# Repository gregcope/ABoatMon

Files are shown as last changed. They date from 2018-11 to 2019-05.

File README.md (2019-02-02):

ABoatMon
========

An Arduno clone based (hence the A) Boat Monitoring solution!

Intro
=====

A reimplementation, and extension of https://github.com/gregcope/piboatmon, as the original consumed too much power.  This is designed with the following goals;
* Be very, very low power and
* Monitor and charge from 12-24V

The present version is made from COTS parts to make life easy at the deign/proto stage.  However the code should be transferable.

Parts
=====
* [Adafruit Ultimate GPS](https://www.adafruit.com/product/746) - any 3.3v UART GPS would do, however needs an enable pin and vbat GPS almanac backup
* [Adafruit Fona](https://www.adafruit.com/product/1946) - any 3.3v UART GSM modem would do, although we do use the battery charging on the fona
* [Low power Atemega 1280 Moteino Mega](https://lowpowerlab.com/shop/product/119) This might fit into lower spec Atmegs, but I have no idea... The [Moteino M0 would work well](https://lowpowerlab.com/shop/product/184), although pin outs need to change.
* [Mini Step Down Regulator Voltag Power Supply Module 4.5v~55v to 5v](https://www.ebay.co.uk/sch/i.html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).  Specifically the one with an enable pin and low power in off mode (<10ua).  Needs to supply 500ma+ (600ma is fine) and deal with 11-30v on the input to work on 12V or 24V systems.  Needs to supply 5V for the lipo charger.  Efficiency is not a massive issue as the regulator is off most of the time, only on to charge occassionally.
* [DS18B20 Waterproof Digital Probe Temperature Sensor with Silicone Cable (higher temp) Thermometer](https://www.ebay.co.uk/sch/i.html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)
* [12V 12mm LED Power Push Button Switch Momentary Waterproof Metal 4 Pin](https://www.ebay.co.uk/sch/i.html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)
* 1200mah LIPO Battery (any single cell LIPO with a JST would do)
* Bilge Switch (any normally closed, simple switch would do)

External Libs
=======

* [Tinygps++](https://github.com/mikalhart/TinyGPSPlus) - A class to deal with GPS
* [Lowpower](https://github.com/LowPowerLab/LowPower) - A class to help with Sleep modes
* Eeprom - Save Eeprom state
* [OneWire](https://github.com/PaulStoffregen/OneWire) - DS18B20 Temp sensor lib

Internal Classes
========
* Config - A class to provide a config object to store Eeprom state
* CRC8 - CRC checksum (for config saving)
* Sleep - Simple wrapper to LowPower sleep
* Buton - A simple button monitor
* Fona - Drive a fona to send data
* Gps - Drive a GPS and feed a TinyGPS++ object with other helper methods
* Led - A simple LED driver
* Lipo - A class to ADC a Lipo value
* Temp - A class with simple, non-sleeping temp measurements
* Vcc - A class to ADC the VCC, as well as enable/disable a regulartor (that drives the 5v Lipo charger)

High Level Logic
================

* Switches is on setup configures all the required parts
* Loop every 8 secs and checks;
   * Start the temp conversion 
   * Lipo volts
   * VCC (and enable regulator if Vcc > 13 and switch off if low)
   * Bilge switch
   * read temp (blocks)
* Every Hour;
   * Checks the above
   * Checks location
* If out of band, send a message as an alarm
* Daily
   * Send a message

VCC logic - Sacrifical Charging
================
The idea is that if VCC is 13v plus then a charge source is on and we can hence enable the regulator.  If the VCC is above REG_ON_VOLTS (13v) enable the regulator to start the LIPO charger.  If below REG_OFF_VOLTS (12.8) stop regulator

Message Sending
================
To save possible expensive bandwidth the message is compressed.  Ideally it would be JSON.  However it is optimised for speed and bandwidth costs.  It needs to be parsed on arrival.

HowTo
=====

1. Open a command terminal, and change cd to where your Ardunio IDE stores code
```cd Documents/Arduino```
2. Clone the repo
```git clone https://github.com/gregcope/ABoatMon.git```
3. Open Ardunio IDE and open ```ABoatMon.ino```

http://arduino.stackexchange.com/questions/348/how-to-organize-my-arduino-projects-structure-for-easy-source-control

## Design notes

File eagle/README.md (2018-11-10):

# Eagle Files

0. Uses Sparkfun DRC file
1. ERC and DRC check clean!
2. Bottom Copper Pour
3. Nets Classes use 24mil width and 16mil clearance
4. Polygons use Isolate 12mil
5. Layer 26 bNames - bottom silkscreen has board dimensions on it

## Design

0. I may add more parts...
1. Uses a MoteinoMega, Adafruit Ultimate GPS and an Adafruit FONA GSM
2. The P-channel Mosfet is designed to power the GPS directly, avoiding the on board regulator
3. The VBAT is on the MotinoMega 3.3V rail to keep the GPS backup circuits powered
4. The JST is for a Lipo battery
5. Their is a 1.8M/3.3M VCC voltage divider to monitor the LIPO, with a 0.1uF capacitor - see [Jeelabs post here](https://jeelabs.org/2013/05/16/measuring-the-battery-without-draining-it/)
6. Terminal Connector is for a simple Bilge switch for the Moteino to monitor
7. Terminal Connector for a Button
8. Terminal Connector for an LED
9. Terminal Connector for a DS18B20 Temp probe powered from a GPIO pin
10. Terminal Connector 12V-24V VCC input
11. A 27M/3.3M voltage divider to measure 30+V on an ADC pin
12. Headers for Fona GSM module
13. Terminal Connector for a 5v cable to connect to the Fona USB charge port
14. There is a jumper to measure the uCurrent the board uses from the LIPO, and also by-pass the switching (aka an on/off switch)
15. There is a jumper to measure the uCurrent the board uses from VCC, and also by-pass the switching (aka an on/off switch)
16. Voltage regulator uses a [holtek HT7463A](http://www.holtek.com/documents/10179/116711/HT7463A_Bv130.pdf)

... What's missing?

No thread is complete without pictures...

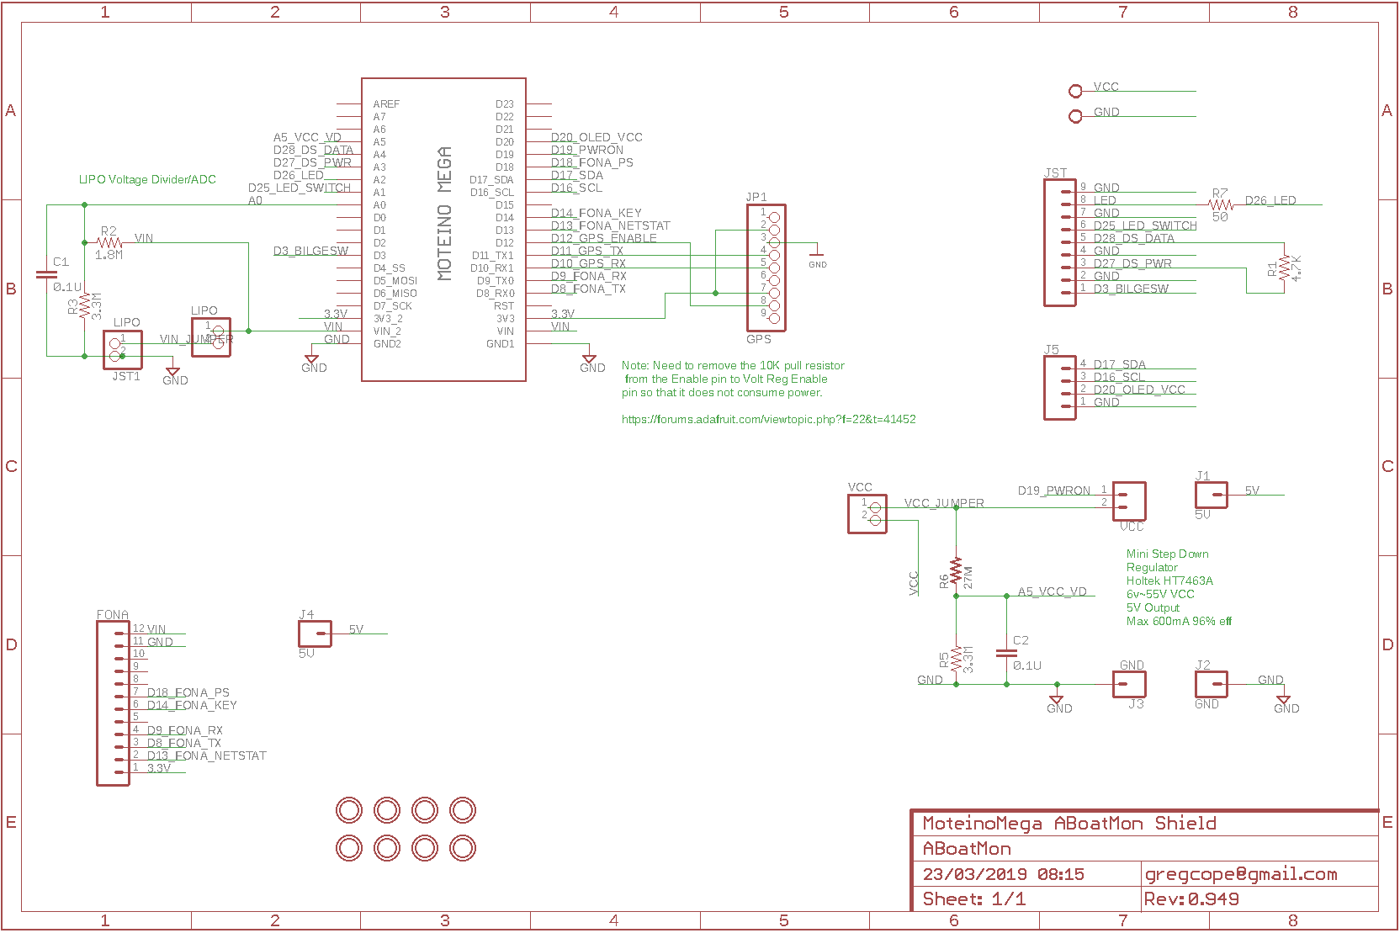
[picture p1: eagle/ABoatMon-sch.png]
Eagle Schematic


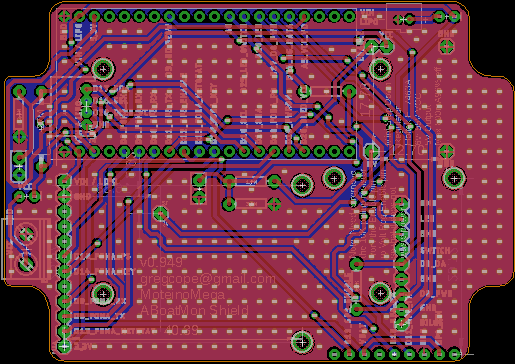
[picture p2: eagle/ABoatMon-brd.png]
Eagle Board


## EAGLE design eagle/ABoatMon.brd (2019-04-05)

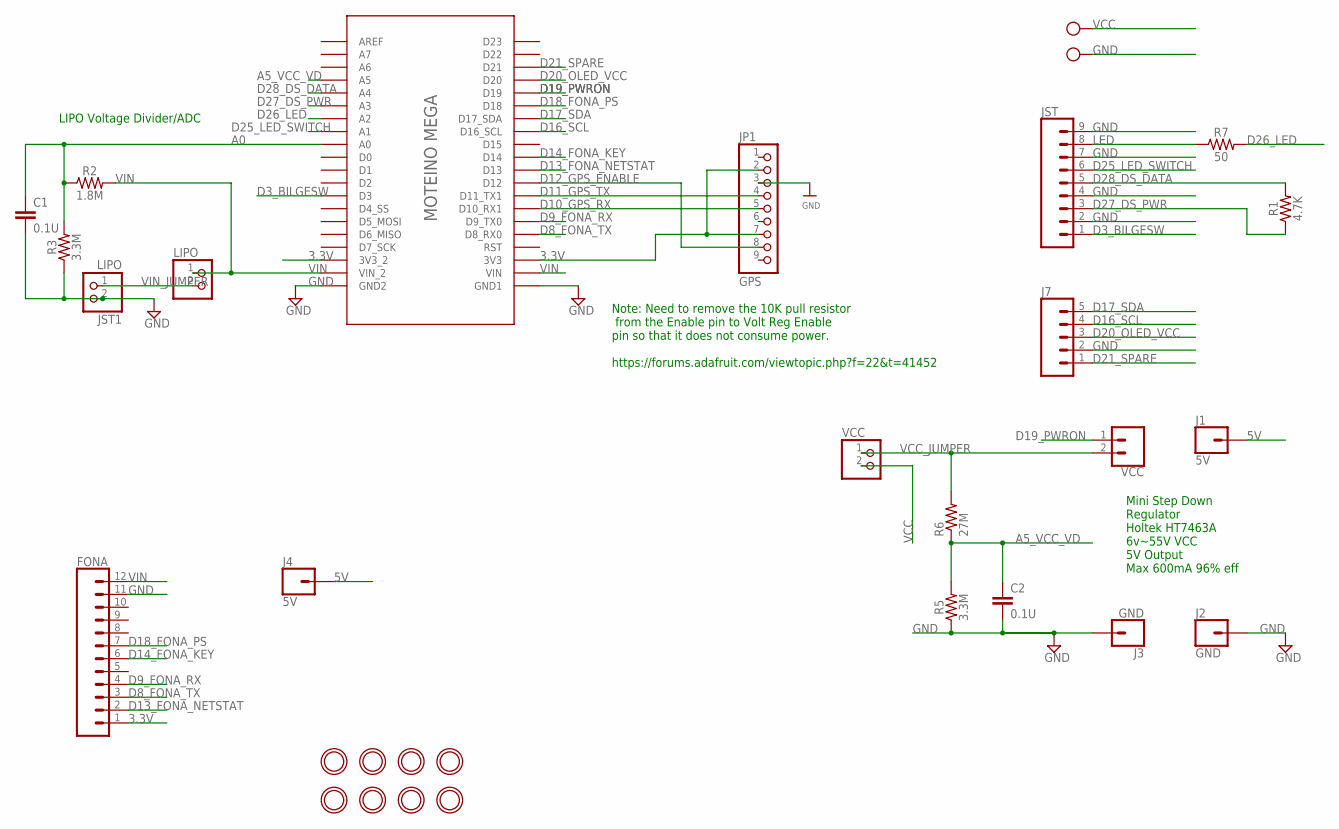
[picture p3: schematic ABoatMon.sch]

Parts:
C1, C2: 0.1U; CAP-PTH-SMALL-KIT
ENABLE: VCC; 1X02
FONA: CONN_12; 1X12
GND: MOUNTINGHOLE2.5; MOUNTINGHOLE_2.5_PLATED
J1, J4: 5V; 1X01
J2, J3: GND; 1X01
J7: CONN_05NO_SILK; 1X05_NO_SILK
JP1: GPS; 1X09_ROUND_70
JST: CONN_09; 1X09
JST1: LIPO; JST-PH-2-THM
LIPO: HEADER-1X2ROUND; 1X02_ROUND
MOTEINO_MEGA: HEADERS; MOTEINO_MEGA_SIMPLE
R1: 4.7K; AXIAL-0.3
R2: 1.8M; AXIAL-0.3
R3, R5: 3.3M; AXIAL-0.3
R6: 27M; 0309/12
R7: 50; AXIAL-0.3
U$1, U$2, U$3, U$4, U$5, U$7, U$8: MOUNTINGHOLE2.5; MOUNTINGHOLE_2.5_PLATED
VCC: HEADER-1X2ROUND; 1X02_ROUND
X1: MKDSN1,5/2-5,08

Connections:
3.3V: FONA.1, JP1.2, JP1.7, MOTEINO_MEGA.3V3, MOTEINO_MEGA.3V3_2
5V: J1.1, J4.1
A0: C1.1, MOTEINO_MEGA.A0, R2.P$1 (1), R3.P$2 (2)
A5_VCC_VD: C2.1, MOTEINO_MEGA.A5, R5.P$2 (2), R6.1
D3_BILGESW: JST.1, MOTEINO_MEGA.D3
D8_FONA_TX: FONA.3, MOTEINO_MEGA.D8 (D8_RX0)
D9_FONA_RX: FONA.4, MOTEINO_MEGA.D9 (D9_TX0)
D10_GPS_RX: JP1.5, MOTEINO_MEGA.D10 (D10_RX1)
D11_GPS_TX: JP1.4, MOTEINO_MEGA.D11 (D11_TX1)
D12_GPS_ENABLE: JP1.8, MOTEINO_MEGA.D12
D13_FONA_NETSTAT: FONA.2, MOTEINO_MEGA.D13
D14_FONA_KEY: FONA.6, MOTEINO_MEGA.D14
D16_SCL: J7.4, MOTEINO_MEGA.D16 (D16_SCL)
D17_SDA: J7.5, MOTEINO_MEGA.D17 (D17_SDA)
D18_FONA_PS: FONA.7, MOTEINO_MEGA.D18
D19_PWRON: ENABLE.1, MOTEINO_MEGA.D19
D20_OLED_VCC: J7.3, MOTEINO_MEGA.D20
D21_SPARE: J7.1, MOTEINO_MEGA.D21
D25_LED_SWITCH: JST.6, MOTEINO_MEGA.A1
D26_LED: MOTEINO_MEGA.A2, R7.P$2 (2)
D27_DS_PWR: JST.3, MOTEINO_MEGA.A3, R1.P$1 (1)
D28_DS_DATA: JST.5, MOTEINO_MEGA.A4, R1.P$2 (2)
GND: C1.2, C2.2, FONA.11, J2.1, J3.1, J7.2, JP1.3, JST.2, JST.4, JST.7, JST.9, JST1.2 (1), MOTEINO_MEGA.GND1, MOTEINO_MEGA.GND_2 (GND2), R3.P$1 (1), R5.P$1 (1), X1.2
LED: JST.8, R7.P$1 (1)
VCC: VCC.2, X1.1
VCC_JUMPER: ENABLE.2, R6.2, VCC.1
VIN: FONA.12, LIPO.1, MOTEINO_MEGA.VIN, MOTEINO_MEGA.VIN_2, R2.P$2 (2)
VIN_JUMPER: JST1.1 (2), LIPO.2

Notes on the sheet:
LIPO Voltage Divider/ADC
Mini Step Down Regulator Holtek HT7463A 6v~55V VCC 5V Output Max 600mA 96% eff
Note: Need to remove the 10K pull resistor from the Enable pin to Volt Reg Enable pin so that it does not consume power. https://forums.adafruit.com/viewtopic.php?f=22&t=41452

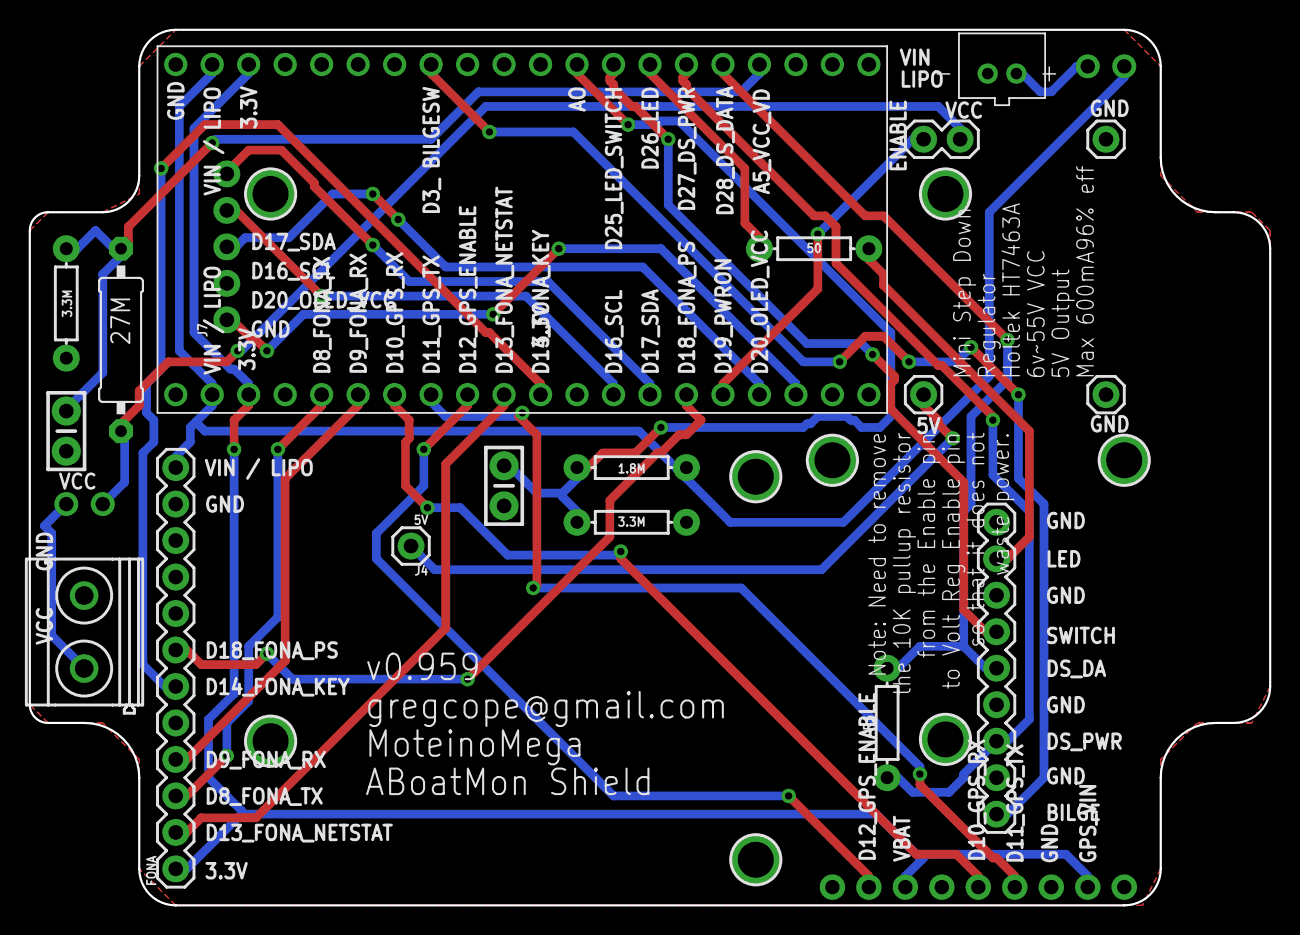
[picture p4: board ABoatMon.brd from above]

Board: 2 copper layers, 86.4 x 61.0 mm, 30 parts (0 on the bottom side), 28 nets.

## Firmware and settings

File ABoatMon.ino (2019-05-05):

/*
 * Greg Cope <gregcope@gmail.com>
 * see; https://github.com/gregcope/ABoatMon
 * 
 * Allot of code pinched from;
 * https://github.com/LowPowerLab/RFM69/blob/master/Examples/MotionMote/MotionMote.ino
 * 
 * TODO
 * Look at https://github.com/cdl1051/DS18B20_NROO/blob/master/DS18B20.h
 * https://lowpowerlab.com/forum/projects/temperature-sensing-with-ds18b20/msg18040/#msg18040
 * https://lowpowerlab.com/forum/moteino/improvedoptimized-ds18b201wire-read/msg14975/#msg14975
 * s
 * 
 */ 

// External includes
// https://github.com/mikalhart/TinyGPSPlus/releases 
#include <TinyGPS++.h>

//#include <NMEAGPS.h>


// internal classes/includes
//#include "Config.h"
#include "Button.h"
#include "Sleep.h"
#include "Gps.h"
//#include "Gns.h"
#include "Lipo.h"
#include "Vcc.h"
#include "Modem.h"
#include "Led.h"
#include "Temp.h"

// PIN defines
#define MEGA_LED 15
#define D12_GPS_ENABLE 12
#define BUTTON_LED 26
#define BUTTON_SWITCH 25
#define BILGE_SWITCH 3 // Other line from BilgeSwitch to GND

//#define LIPO_VOLTAGE_DIVIDER 24 // D24 is same as A0
const int LIPO_VOLTAGE_DIVIDER = 0;

// DS18B20
// Red connects to 27, Blue/Black connects to ground and Yellow/White (data) to 28
#define TEMP_POWER 27 // PA3
#define TEMP_DATA 28 // PA4

#define VCC_12V_24V_VOLTAGE_DIVIDER A5 
#define VCC_12V_24V_ENABLE 19

#define FONA_KEY 14
#define FONA_PS 18
#define FONA_NETSTAT 13

//oled https://lowpowerlab.com/forum/moteinomega/moteino-(mega)-oled-and-u8g/msg7305/#msg7305
#define OLED_SDA 17
#define OLED_SCL 16
#define OLED_POWER 20

// Static defines
#define FOURMIN_CYCLES 30 // 8 sec sleep * 30 cycles = 240 secs or 4 mins
#define HOUR_CYCLES 450 // 8 sec sleep * 450 cyles == 3600 secs or 1 hour
#define DAILY_CYCLES 10800 // 8 sec sleep * 10800 cycles == 86400 secs or 1 day

//#define INITIAL_GPS_FIX_TIMEOUT_MSECS 300000 // time to try and get a fix in msecs is 300 secs, or 5 mins
//#define INITIAL_GPS_FIX_TIMEOUT_MSECS 600000 // time to try and get a fix in msecs is 600 secs, or 10 mins
#define INITIAL_GPS_FIX_TIMEOUT_MSECS 900000 // time to try and get a fix in msecs is 900 secs, or 15 mins
#define INITIAL_GPS_FIX_TIMEOUT_MSECS 1200000 // time to try and get a fix in msecs is 1200 secs, or 20 mins

//#define UPDATE_GPS_FIX_TIMEOUT_MSECS 15000 // 15 secs
#define UPDATE_GPS_FIX_TIMEOUT_MSECS 60000 // 60 secs
#define UPDATE_GPS_NUMBER_OF_FIXES 30 // 10 secs

// Alarm settings
#define LOW_TEMP_ALARM 2 // or could be 0 or -1
#define HIGH_TEMP_ALARM 85
#define REG_OFF_VOLTS 12.8
#define REG_ON_VOLTS 13
#define VCC_LOW_ALARM 11.2
#define LIPO_BATTERY_ALARM 3.1


// debug functions
#define DEBUG(input)   {Serial.print(input); Serial.flush();}
#define DEBUGln(input) {Serial.println(input); Serial.flush();}

// Objects

// tinyGPS is a nmea feed parser
Sleep sleep;
Gps gps(D12_GPS_ENABLE);
//Gns gns(D12_GPS_ENABLE);
Lipo lipo(LIPO_VOLTAGE_DIVIDER);
Vcc vcc(VCC_12V_24V_ENABLE, VCC_12V_24V_VOLTAGE_DIVIDER);
Modem modem(FONA_KEY);
Led megaLed(MEGA_LED);
Led switchLed(BUTTON_LED);
Temp temp(TEMP_POWER, TEMP_DATA);
Button bilgeSwitch(BILGE_SWITCH);
Button switchButton(BUTTON_SWITCH);

// Cycle Vars
unsigned long cycleCount = 0;
//byte fourMinCycleCount = 0;
//unsigned int hourCycleCount = 0;
//unsigned long NOW = 0;

// GPS / Nmea vars
//unsigned long nmeaSentenceTimeOutMs = 0;
//boolean nmeaSentenceTimeoutReached = false;
//double fixLat = 181; // invalid Lat
//double fixLng = 181; // invalid Lat
//double alarmLat = 181; // invalid Lat
//double alarmLng = 181; // invalid Lat
double orgLat = 0; // Last recorded Lat
double orgLon = 0; // Last recorded lon
double newLat = 0;
double newLon = 0;
double distance = 10000; // distance moved (default)

// LipoBattery, Vcc and Temp variables & buffer strings
float lipoVolts = 0;
char lipoStr[10];
float vccVolts= 0;
char vccStr[10];
char tempStr[11];
float tempInC;
char bilgeStr[4];
char latStr[30]; // lat string
char lonStr[30]; // lon string
char distanceStr[30];
//char disStr[6]; // in 99999m distance in 24hrs ... would not work in a fast yacht!


// Message varriables
//String messageStr = "";
char messageStr[200];
char dateTimeStr[19];

boolean sendLipoMessage = false;
boolean sendHighTempMessage = false;
boolean sendLowTempMessage = false;
boolean sendBilgeMessage = false;
boolean sendNoGpsFixMessage = false;
boolean sendGeoFenceMessage = false;
boolean sendVccMessage = false;
boolean sendDailyMessageFlag = false;

//
// Code from here on ...
//
void setup() {
  Serial.begin(9600);
  Serial.flush();
  DEBUGln("setup Start 15");
  modem.on();
  //modemOnMillis = millis();
  temp.init();
  //yep burn CPU for 1/2 sec... to let stuff settle
  delay(500);
  gps.init();
  // gns.init(); // don't need a neoGPS init - not using antenna output
  gps.getInitialFix(INITIAL_GPS_FIX_TIMEOUT_MSECS);
  //gns.getInitialFix(INITIAL_GPS_FIX_TIMEOUT_MSECS);
  DEBUGln("setup Done");
}

void loop() {

  // start of loop
  megaLed.on();
  DEBUGln("loop ...");

  // assign some defaults
  sprintf(lipoStr, "LIPO:5.0v");
  sprintf(vccStr, "VCC:50.0v");
  sprintf(tempStr, "TEMP:99.9c");
  sprintf(bilgeStr, "B:F");
  tempInC = -100;

  // do checks
  doShortChecks();
  doHourlyChecks();
  sendDailyMessage();

  // if we need to
  sendMessage();

  // done
  megaLed.off();
  sleep.kip8Secs();
}

void checkLipo(void) {

  // read lipo battery
  lipoVolts = lipo.read();

  // check if alarm
  if ( lipoVolts <= LIPO_BATTERY_ALARM ) {
    sendLipoMessage = true;
  }
  // format string ... even if we do not need it 
  dtostrf(lipoVolts,3,1,lipoStr);
  //DEBUG("lipoVolts: ");
  //DEBUGln(lipoVolts);
}

void checkVcc(void) {
  // read Vcc and enable regulator
  // do this each short iteration as we
  // will have to wait for temp anyway
  // so might either micro sleep or do something useful!
  vccVolts = vcc.read();
  DEBUG("vcc is: ");
  DEBUG(vccVolts);
  DEBUGln("V");

  // check reg
  if ( vccVolts > REG_ON_VOLTS ) {
   vcc.regOn();
  } else if (vccVolts < REG_OFF_VOLTS ) {
   vcc.regOff(); 
  }
  if (vccVolts < VCC_LOW_ALARM ) {
   //DEBUGln("Vcc is too low!!!");
   sendVccMessage = true;
    // disbale regulator 
  }
   // format string ... even if we do not need it 
  dtostrf(vccVolts,3,1,vccStr);
  //DEBUG("vccVolts: ");
  //DEBUGln(vccVolts);
}

void checkBilge(void) {
  // check bilge switch
  if ( bilgeSwitch.isClosed() ) {
    // oh no ....
    sendBilgeMessage = true;
    sprintf(bilgeStr, "B:T");
  }
  //DEBUG("bilgeStr: ");
  //DEBUGln(bilgeStr);  
}

void checkReadTemp(void) {

  // blocking read temp
  tempInC = temp.read();
  if ( tempInC >= HIGH_TEMP_ALARM ) {
    sendHighTempMessage = true;
    DEBUGln("HIGH TEMP ALARM");
  } else if ( tempInC <= LOW_TEMP_ALARM ) {
    sendLowTempMessage = true;
    DEBUGln("LOW TEMP ALARM");  
  }
  dtostrf(tempInC,3,1,tempStr);
  //DEBUG("tempStr: ");
  //DEBUGln(tempStr);
  
}

boolean doShortChecks(void) {

  // function to do short checks each time
  // returns wether to send a message
  DEBUGln("doShortChecks");
  
  checkAsyncTemp();
  checkLipo();
  checkVcc();
  checkBilge();
  checkReadTemp();
  checkLocation();
  // update cyclecount and return
  cycleCount++;
  return true;  
}

void checkAsyncTemp(void) {

  // kick off temp conversion
  temp.startConvert();
  
}

//boolean doLongChecks(void) {

  // function to do long checks
  // returns weather to send a message

  //if ( cycleCount <= FOURMIN_CYCLES ) {
    // if not time yet, return false
    //return false;
  //}

  // otherwise time to do long checks
  //DEBUGln("doLongChecks: ");

  //checkLocation();
  //gps.getUpdatedFix(UPDATE_GPS_FIX_TIMEOUT_MSECS, UPDATE_GPS_NUMBER_OF_FIXES);  

  //return true;
//}

boolean doHourlyChecks(void) {
  // function to do hourly checks
  // returns wether to send a message

  if ( cycleCount <= HOUR_CYCLES ) {
    DEBUG("cycleCount is: ");
    DEBUG(cycleCount);
    DEBUGln(", doHourlyChecks : Not running now!");
    // if not time yet, return false
    return false;
  }
  // time to do hour checks
  DEBUGln("doHourlyChecks: ");

  checkLocation();
    
  // TODO: calc number of cycles left to get to hourly checks
  
  // send a message?
  return true;
}

boolean sendDailyMessage(void) {

  if ( cycleCount <= DAILY_CYCLES ) {
    DEBUG("cycleCount is: ");
    DEBUG(cycleCount);
    DEBUGln(", sendDailyMessage : Not running now!");
    // if not time yet, return false
    return false;
  }
  // function to do daily checks
  // always returns true as we want to send a message
  DEBUGln("set sendDailyMessageFlag to true");
  // send a message?
  sendDailyMessageFlag = true;
  return true;
}

void checkLocation(void) {

  // update location
  // TODO: Logic if no updated fix
  gps.getUpdatedFix(UPDATE_GPS_FIX_TIMEOUT_MSECS, UPDATE_GPS_NUMBER_OF_FIXES);
  // check location vs last location
  // work out distance(orgLat, orgLon, lat, lon);
  //newLat = gps.getLat();
  //newLon = gps.getLon();
  gps.getLocation(newLat, newLon);
//  distance = gps.distanceMoved(orgLat, orgLon);
//  distance = gps.haversine(newLat, newLon, orgLat, orgLon);
  gps.distanceMoved(orgLat, orgLon, distance);
  // save where we are now
  orgLat = newLat;
  orgLon = newLon;

  // convert Double to string
  // https://ukhas.org.uk/guides:common_coding_errors_payload_testing
  dtostrf(newLat, 10, 6, latStr);  //first number is length, last is numbers after decimal
  dtostrf(newLon, 10, 6, lonStr);

  dtostrf(distance, 9,2, distanceStr);
}

void sendMessage(void) {
  // check to send a message?
  // basically ANY alarms OR daily message
  if ( !sendLipoMessage || !sendHighTempMessage || !sendLowTempMessage || !sendBilgeMessage || !sendNoGpsFixMessage || !sendGeoFenceMessage || !sendVccMessage || !sendDailyMessageFlag ) {
    // no need to send a message
    //return;  
  }

  // send a message!!!!
  // like 20190127T20:20:20-LIPO:5.0v-VCC:50.0v-TEMP:99.9c,BILGE:OK,LAT:NNNNN:LON:YYYYYY:DIS:NNNNNm
  
  //Get a dateTime String
  sprintf(dateTimeStr, gps.getdateTime());

  // going to try and pinch some power;
  vcc.regOn();

  //Put the message together
  // first 1 is API version
  // https://docs.rockblock.rock7.com/docs/compressing-your-data
  // RockBLOCK 9603 would be nice
  // basically send ints 13.7v should be 137, ie drop the V, and decimal
  sprintf(messageStr, "'1,%s,%sv,%sv,%sc,%s,%s,%s,%sm'", dateTimeStr, lipoStr, vccStr, tempStr, bilgeStr, latStr, lonStr, distanceStr);
  removeSpaces(messageStr);
  DEBUG("Message is: ");
  DEBUGln(messageStr);
  
  // message sent tidy up
  // done swich off regulator
  vcc.regOff();
  
  // clear flags
  sendLipoMessage = false;
  sendHighTempMessage = false;
  sendLowTempMessage = false;
  sendBilgeMessage = false;
  sendNoGpsFixMessage = false;
  sendGeoFenceMessage = false;
  sendVccMessage = false;
  sendDailyMessageFlag = false;
  // done
}

// https://www.geeksforgeeks.org/remove-spaces-from-a-given-string/
void removeSpaces(char *str) { 
    // To keep track of non-space character count 
    int count = 0; 
  
    // Traverse the given string. If current character 
    // is not space, then place it at index 'count++' 
    for (int i = 0; str[i]; i++) 
        if (str[i] != ' ') 
            str[count++] = str[i]; // here count is 
                                   // incremented 
    str[count] = '\0'; 
} 

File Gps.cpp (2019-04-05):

#include <Arduino.h>
#include "Gps.h"

Gps::Gps(byte pin) {
  // Constructor
  // Takes an int as pin to power up
  _powerPin = pin;
  pinMode(_powerPin, OUTPUT);
}

void Gps::init(void) {
  // 0 = Invalid, 1 = GPS fix, 2 = DGPS fix
  // 1 in this example
  // $GPGGA,064951.000,2307.1256,N,12016.4438,E,1,8,0.95,39.9,M,17.8,M,,*65
  DEBUGln("Init ... doing TinyGPSCustom ")
  TinyGPSCustom fixqual(nmea, "GPGGA", 6); // $GPGGA sentence, 6th element
  // report antenna
  // looking for
  // $PGTOP,11,3,6F
  // 1 = short, 2 = internal, 3 = external
  TinyGPSCustom antenna(nmea, "PGTOP", 2); // PGTOP sentence, 2nd element
}

boolean Gps::on(void) {
  // Switch device on by putting pin HIGH
  digitalWrite(_powerPin, HIGH);
  _powerState = true;
  Serial1.begin(9600);
  Serial1.flush();
  Serial.println("GPS device on!");
  Serial.flush();
  setupGPS();
  if ( Serial1.available() > 0) {
    // spitting something out so assume on!
    return true;
  } else {
    return false;
  }
}

void Gps::off(void) {
  // turn off the Device by putting pin LOW
  digitalWrite(_powerPin, LOW);
  Serial1.flush();
  //delay(500);
  _powerState = false;
  Serial.println("GPS device off!");
}

boolean Gps::isOn(void) {
  // return state
  // on == true
  // off == false
  //DEBUG("gps state is:");
  //DEBUGln(_powerState);
  return _powerState;
}

boolean Gps::updateFix(unsigned long timeout, int updates) {

  // takes a nmea timeout
  // assume timeout is 12 secs - 12000
  // run until the nmea object is updated
  // at least 10 times?
  // return true or false

  DEBUG("updateFix: ")

  nmeaTimeoutMs = millis() + timeout;
  nmeaUpdates = nmea.sentencesWithFix() + updates;

  // make sure GPS is on (may not be needed)
  if ( !isOn() ) {
    //DEBUGln("gps is off, turning it on")
    on();
  }

  //DEBUG("nmeaUpdates: ")
  //DEBUG(nmeaUpdates)
  //DEBUG(", nmea.sentencesWithFix()")
  //DEBUG(nmea.sentencesWithFix())
  //DEBUG(", nmeaTimeoutMs: ")
  //DEBUG(nmeaTimeoutMs)
  //DEBUG(", millis is: ")
  //DEBUGln(millis())

  // https://forum.arduino.cc/index.php?topic=503368.0
  // currentMillis = millis();  //get the current time
  //if (currentMillis - startMillis >= period)  //test whether the period has elapsed
  // {
  //  analogWrite(ledPin, brightness);    //set the brightness of the LED
  //  brightness += increment;    //will wrap round from 255 to 0 because brightness is an unsigned data type
  //  startMillis = currentMillis;  //IMPORTANT to save the start time of the current LED brightness
  //}

  while ( nmeaTimeoutMs > millis() ) {

    drainNmea();

    //if ( nmea.location.isUpdated() ) {
    //  // if the object was updated, update counter
    //  DEBUGln("nmea.location.isUpdated")
    //  nmeaUpdated ++;
    //}

    // when we have 10 fix updates (10 secs ish)
    // return
    //DEBUG("nmea.sentencesWithFix():")
    //DEBUGln(nmea.sentencesWithFix());
    if ( nmeaUpdates <= nmea.sentencesWithFix() ) {
      DEBUG("Got nmea updates: ")
      DEBUGln(updates);
      return true;
    }

  }

  DEBUG("nmeaUpdates: ")
  DEBUG(nmeaUpdates)
  DEBUG(", nmea.sentencesWithFix(): ")
  DEBUG(nmea.sentencesWithFix())
  DEBUG(", nmeaTimeoutMs: ")
  DEBUG(nmeaTimeoutMs)
  DEBUG(", millis is: ")
  DEBUG(millis())
  DEBUG(", fixqual: ");
  DEBUG(fixqual.value());
  DEBUG(", antenna: ");
  DEBUGln(antenna.value());

  if ( ( nmeaUpdates - nmea.sentencesWithFix() ) < 10 ) {
    // got some fixes, just not 10 ...
    return true;
  }
  // fell out of timeout with insufficient nmea updates
  return false;
}

boolean Gps::getUpdatedFix(unsigned long timeout, int updates) {

  on();
  updateFix(timeout, updates);
  off();

  DEBUG("getUpdatedFix: ");

  if ( nmea.location.isUpdated() ) {
    printGPSData();
    return true;
  } else {
    // give it another go
    //DEBUGln("No GPS update - giving it another go updateFix()")
    //updateFix(timeout);
    //if ( nmea.location.isUpdated() ) {
    //printGPSData();
    //} else {
    DEBUGln("No GPS update")
    return false;
    //}
  }
  return true;
}

unsigned long Gps::getInitialFix(unsigned long timeout) {

  // takes a gps fix tmeout
  // returns millis to get a fix OR zero if failed

  gpsFixTimeoutReached = false;
  gpsTimerStart = millis();
  gpsFixTimeoutMs = gpsTimerStart + timeout;
  gpsTimeToFixMs = 0;
  initialHDOP = 0;
  finalHDOP = 0;
  hdop = 0;
  now = 0;
  //nmeaUpdated = 0;

  on();

  DEBUGln("getInitialFix");

  while ( !gpsFixTimeoutReached ) {
    // capture now
    now = millis();

    // update the nmea object lots of times
    if ( updateFix(12000, 10) ) {
      // do nothing - it works
    } else {
      // no nmea ... bail
      // no updateds bail
      DEBUGln("no updated fixes")
      //return 0;
    }
    //while ( nmeaUpdated < 9 ) {
    //drainNmea();
    //   if ( nmea.hdop.isUpdated() ) {
    //     nmeaUpdated ++;
    //     DEBUG(".");
    //   }
    // }

    // see if we got a sensible fix
    DEBUG("getInitialFix: ");
    DEBUG(now);

    DEBUG(", hdop.isUpdated: ");
    if ( nmea.hdop.isUpdated() ) {
      DEBUG("TRUE");
    } else {
      DEBUG("FALSE");
    }

    hdop = nmea.hdop.value();

    DEBUG(", hdop.age: ");
    DEBUG(nmea.hdop.age());

    DEBUG(", loc.isUpdated: ");
    if (nmea.location.isUpdated() ) {
      DEBUG("TRUE");
    } else {
      DEBUG("FALSE");
    }

    DEBUG(", HDOP:");
    DEBUG(hdop);
    DEBUG(", Serial1.ava: ");
    DEBUG(Serial1.available());
    DEBUG(", ACCEPTABLE HDOP: ");
    DEBUG(ACCEPTABLE_GPS_HDOP_FOR_FIX);
    DEBUG(", initial HDOP: ");
    DEBUG(initialHDOP);
    DEBUG(", gpsFixTimeoutMs: ");
    DEBUG(gpsFixTimeoutMs);
    DEBUG(", nmea.passCksum: ");
    DEBUG(nmea.passedChecksum());
    DEBUG(", fixqual: ");
    DEBUG(fixqual.value());
    DEBUG(", antenna: ");
    DEBUGln(antenna.value());

    // do we have an acceptable fix yet?
    if ( ( hdop != 0 && hdop <= ACCEPTABLE_GPS_HDOP_FOR_FIX )  && initialHDOP == 0 ) {
      DEBUGln("gpsFix is true - we have an inital acceptable fix!!!!");
      DEBUG("nmea.hdop.value(): ");
      DEBUGln(hdop);
      // stops this if statement next time
      initialHDOP = hdop;
      gpsTimeToFixMs = now - gpsTimerStart;
      DEBUG("gpsTimeToFixMs: ");
      DEBUGln(gpsTimeToFixMs);
      printGPSData();
      //off();
      //return gpsTimeToFixMs;
    }

    // do we have a good fix?
    if ( hdop != 0 && hdop <= GOOD_GPS_HDOP_FOR_FIX ) {
      DEBUGln("gpsFix is true, hdop low - we have a good fix!!!!");
      DEBUG("nmea.hdop.value(): ");
      DEBUGln(hdop);
      finalHDOP = hdop;
      gpsTimeToFixMs = now - gpsTimerStart;
      DEBUG("gpsTimeToFixMs: ");
      DEBUGln(gpsTimeToFixMs);
      printGPSData();
      off();
      return gpsTimeToFixMs;
    }

    // we reached the timeout ... too bad
    if ( ( gpsFixTimeoutMs <= now ) && initialHDOP == 0) {

      //gpsFixTimeoutReached = true;
      // we failed to get a fix ...
      DEBUGln("We failed to get fix !!!");
      off();
      return 0;
    }
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

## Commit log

2016-05-03 Added Device Class
2016-05-03 Added Device Class to README
2016-05-03 Added LED, ChargerPin and GPS setup
2016-06-01 Added start method to Device
2016-06-11 Changed GPS Power Pin
2016-06-11 Added LED switch and Bilge Switch logic
2016-06-11 Refined and tested bilge Switch logic and added message logic
2016-06-11 trying to sort battery monitoring
2016-06-12 Finally got the VoltDivider working, and string concat\!
2016-06-15 Changed name to lipoBatt...
2016-06-15 Changed name to lipoBatt... and a few I missed
    [ABoatMon.ino]
2016-07-01 Lots of changes, inc GPS fix timeout
    [ABoatMon.ino]
2017-04-14 Added logic to check for fix
    [ABoatMon.ino, Sleep.cpp]
2017-05-07 Voltage divider working, GPS on P-Mosfet
2017-09-23 added v0.1 eagle files
    [MoteinoMegaGPSSheild.brd, MoteinoMegaGPSSheild.sch]
2017-09-24 V0.2 No errors, Bottom layer copper pour
    [MoteinoMegaGPSSheild.brd, MoteinoMegaGPSSheild.sch]
2017-09-24 v0.3 ... GSM plus right Mega headers
    [MoteinoMegaGPSSheild.brd, MoteinoMegaGPSSheild.sch]
2017-09-25 Removing PDFs
    [MoteinoMegaGPSSheild.brd, MoteinoMegaGPSSheild.sch]
2017-09-26 Added v0.61
    [MoteinoMegaGPSSheild.brd, MoteinoMegaGPSSheild.sch]
2017-09-30 V0.91. Changed netclasses, autorouted, tidied names. Bar one Width and a few angle errors passes sparkfun and oshpark DRC rules
    [MoteinoMegaGPSSheild.brd, MoteinoMegaGPSSheild.sch]
2017-09-30 V0.97 - Silkscreen fixes
    [MoteinoMegaGPSSheild.brd, MoteinoMegaGPSSheild.sch]
2017-10-01 V0.98, schematic layout tweaks, corrected GSM power error, removed GSM power
    [MoteinoMegaGPSSheild.brd, MoteinoMegaGPSSheild.sch]
2017-10-01 Added reverse polarity protection and fuse, as well as GSM FET
    [MoteinoMegaGPSSheild.brd, MoteinoMegaGPSSheild.sch]
2017-10-02 Moved things around, changed P-fets
    [MoteinoMegaGPSSheild.brd, MoteinoMegaGPSSheild.sch]
2017-10-07 Changed Resistor shapes
    [MoteinoMegaGPSSheild.brd, MoteinoMegaGPSSheild.sch]
2017-10-08 Added current limiting resistors
    [MoteinoMegaGPSSheild.brd, MoteinoMegaGPSSheild.sch]
2017-10-13 Routed 100%, finally
    [MoteinoMegaGPSSheild.brd, MoteinoMegaGPSSheild.sch]
2017-10-13 tNames changes
    [MoteinoMegaGPSSheild.brd]
2017-10-21 DS wiring
2018-05-19 eagle updates
    [MoteinoMegaGPSSheild.brd, MoteinoMegaGPSSheild.sch]
2018-06-09 New eagle files
    [ABoatMon.brd, ABoatMon.sch]
2018-06-15 Another go...
    [ABoatMon.brd, ABoatMon.sch]
2018-07-08 v 2.99
    [ABoatMon.brd]
2018-07-09 simplified to use GPS enable pin, reduce BOM. Need to remove 10K pull-up on Enable pin
    [ABoatMon.brd, ABoatMon.sch]
2018-07-09 doco added
    [ABoatMon.brd, ABoatMon.sch]
2018-07-09 Smaller layout, swapped gps
    [ABoatMon.brd, ABoatMon.sch]
2018-07-24 Silkscreen updates
    [ABoatMon.brd, ABoatMon.sch]
2018-07-24 Silkscreen updates+routing
    [ABoatMon.brd]
2018-10-28 v2.99 - complete relayout
    [ABoatMon.brd, ABoatMon.sch]
2018-10-28 v2.99 gerbers sent to JLCPCB
    [ABoatMon.brd]
2018-10-28 Added the other 3v rail, silkscreen fixes
    [ABoatMon.brd, ABoatMon.sch]
2018-10-28 Added screw term info
2018-10-28 email addy change
    [ABoatMon.sch]
2018-10-29 more design info
    [ABoatMon.brd]
2018-11-03 LIPO jumper correction. Reroute+better ground pours
    [ABoatMon.brd, ABoatMon.sch]
2018-11-03 Doh. fona swapped round, VCC header fix, better GND pour
    [ABoatMon.brd, ABoatMon.sch]
2018-11-03 fixed a DRC issue
    [ABoatMon.brd]
2018-11-04 Addig sonoff case datasheet
2018-11-09 v0.649 - rotate gps, fona, move TH parts, remove 5v and GND screw
    [ABoatMon.brd, ABoatMon.sch]
2018-11-11 v0.649 - moved screw terminal headers
    [ABoatMon.brd, ABoatMon.sch]
2018-11-17 Silkscreen improvements
    [ABoatMon.brd, ABoatMon.sch]
2018-11-17 Silkscreen improvements II
    [ABoatMon.brd, ABoatMon.sch]
2018-11-17 Silkscreen typo
    [ABoatMon.brd]
2018-11-17 lots of gnd vias
    [ABoatMon.brd]
2018-11-21 Silkscreen fixes for D18, D19
    [ABoatMon.brd]
2018-11-23 Silkscreen fixes for D18, D19 II
    [ABoatMon.brd]
2018-11-23 changed layout for sonoff box
    [ABoatMon.brd, ABoatMon.sch]
2018-11-23 removing old board
    [MoteinoMegaGPSSheild.brd, MoteinoMegaGPSSheild.sch]
2018-12-08 Moved boxmounting holes 3mm
    [ABoatMon.brd, ABoatMon.sch]
2018-12-09 starting again
    [ABoatMon.brd, ABoatMon.sch]
2018-12-17 bigger JST, added 4.7K
    [ABoatMon.brd, ABoatMon.sch]
2018-12-17 DRC, ERC pass
    [ABoatMon.brd, ABoatMon.sch]
2018-12-18 Setup GPS and lipo code
    [ABoatMon.brd, ABoatMon.sch]
2018-12-20 Fixed gps fix code ...
    [ABoatMon.ino, Gps.cpp, Sleep.cpp]
2018-12-20 lipo code vaguly working
2018-12-20 updated lipo code
2018-12-23 sleep/resume works. Fix borked - need to update gps/nmea object before reusing it
    [ABoatMon.ino, Gps.cpp, Sleep.cpp]
2018-12-23 sorta fixed gps update
    [Gps.cpp]
2018-12-25 sorta fixed gps update part deux
    [ABoatMon.ino, Gps.cpp]
2019-01-02 changed size of endy bit
    [ABoatMon.brd]
2019-01-02 rerouting to add more vias
    [ABoatMon.brd]
2019-01-03 removed extra 3.3v labels
    [ABoatMon.brd, ABoatMon.sch]
2019-01-05 Slikscreenfixes, code into debug mode
    [ABoatMon.brd]
2019-01-12 Initial commit of LED, and GPS fixes
    [ABoatMon.ino, Gps.cpp, Led.cpp]
2019-01-13 Added Mote LED, GPS optimsations
2019-01-18 moved 9 pin jst
    [ABoatMon.brd]
2019-01-20 Temp refactor ... old version does not work ...
    [ABoatMon.ino, Temp.cpp]
2019-01-20 Temp refactor ... works, too much code
    [Temp.cpp]
2019-01-22 Button class, remove Device
2019-01-22 Comments update for Led.cpp
2019-01-24 Button comments
2019-01-26 Button fixpwdpwd
2019-01-26 moved large JST
    [ABoatMon.brd, ABoatMon.sch]
2019-02-02 message logic
    [ABoatMon.brd, ABoatMon.sch]
2019-02-03 eagle jst added
    [ABoatMon.brd]
2019-02-03 added JST - drc issues still
    [ABoatMon.brd, ABoatMon.sch]
2019-02-03 v0.899 board design - irgnoring DRC checks
2019-02-03 added logic and add missing line
    [Sleep.cpp]
2019-02-03 distance debug and lon wrong...
    [ABoatMon.ino]
2019-02-09 fixed vcc
    [ABoatMon.brd, ABoatMon.sch]
2019-02-13 Improved lipo formula
2019-02-13 Improved lipo formula removed debug
2019-02-23 Gns on, off, init, powerStat
2019-03-23 latest board
2019-04-05 v0.959 board layout, moved to 0.1 not jst
    [ABoatMon.brd, ABoatMon.sch]

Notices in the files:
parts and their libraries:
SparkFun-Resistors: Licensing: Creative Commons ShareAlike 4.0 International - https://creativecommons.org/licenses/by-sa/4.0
